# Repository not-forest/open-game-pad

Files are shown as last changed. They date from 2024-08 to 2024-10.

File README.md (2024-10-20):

# Open Game Pad

Low-cost, DIY game controller. This project enables anyone to build a custom game pad using affordable components and open hardware principles. The repository contains all necessary files, including PCB designs and firmware.

## Contents
- `pcb/`: PCB design files
- `src/`: Firmware source code
- `usbdrv/`: USB driver files
- `docs/`: Images

## Images

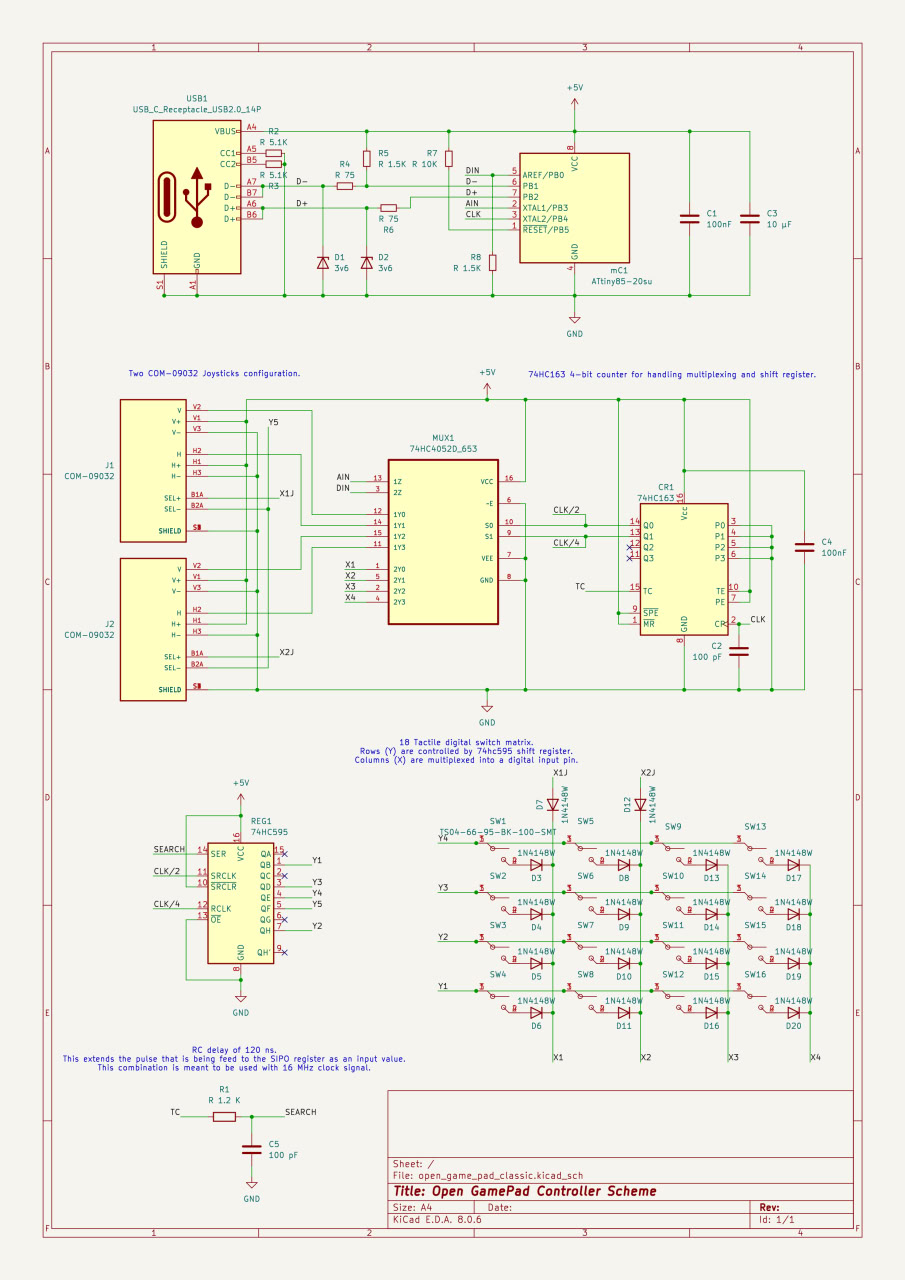
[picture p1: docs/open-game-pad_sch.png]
Schematic

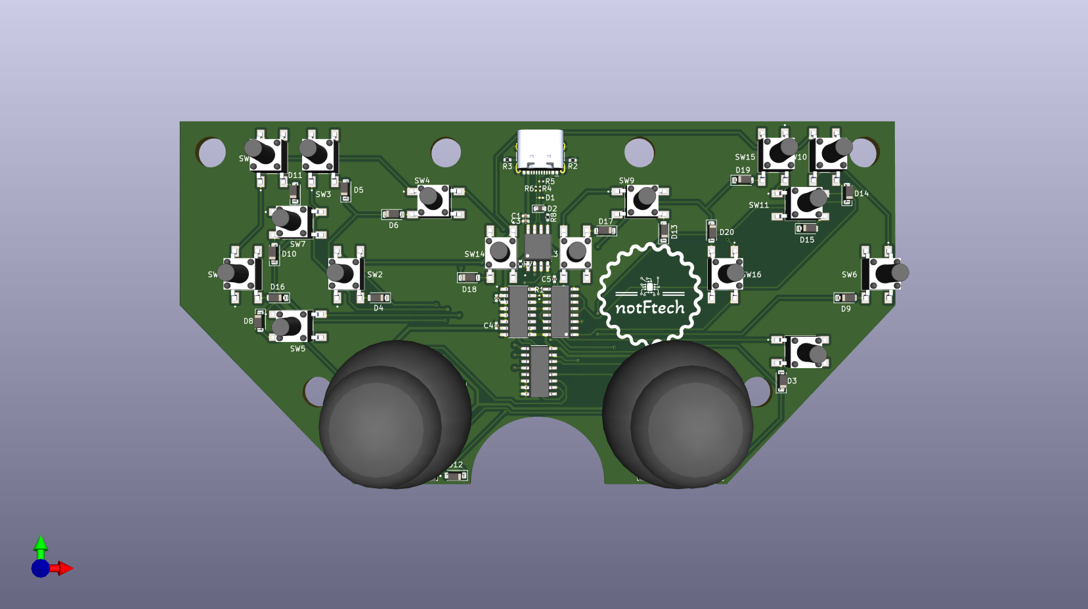
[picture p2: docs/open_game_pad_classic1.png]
View 1

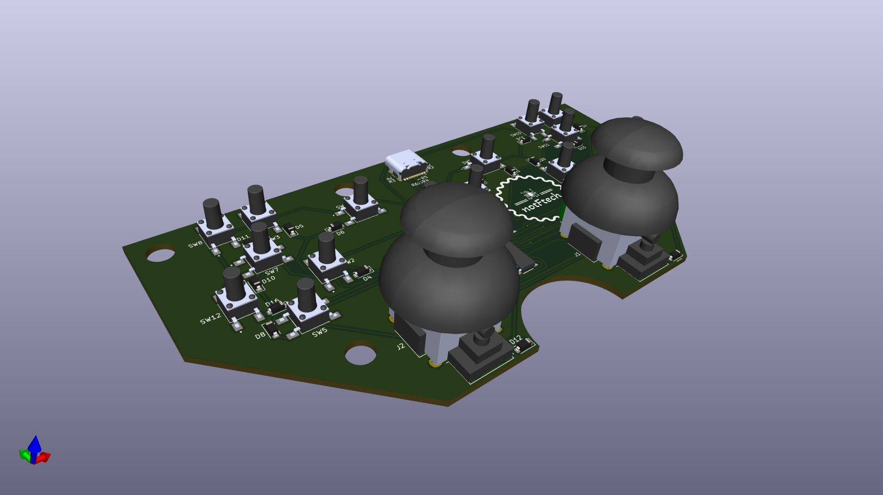
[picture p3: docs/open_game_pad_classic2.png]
View 2

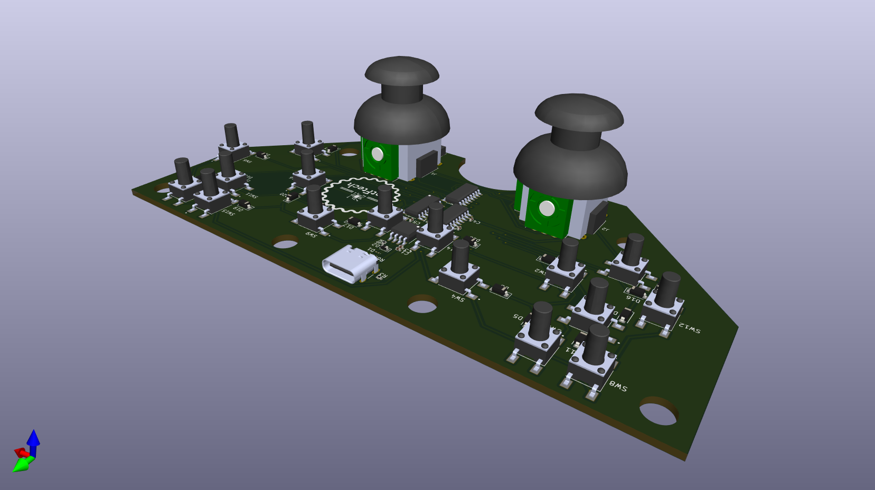
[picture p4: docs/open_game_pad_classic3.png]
View 3


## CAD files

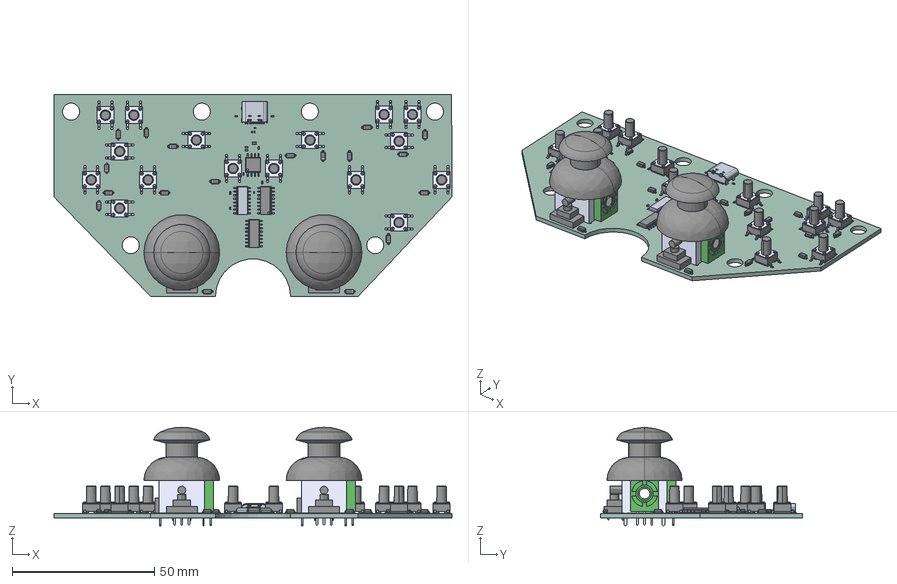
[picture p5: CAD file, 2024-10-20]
pcb/open_game_pad_classic/open_game_pad_classic.step
140.0 x 71.0 x 34.7 mm
R_0402_1005Metric x 4
C_0402_1005Metric x 5
D_SOD_123 x 18
TS04-66-95-BK-100-SMT x 16
DS90C031TM
D_0603
D16
74HC390D,652
ATTINY85-20SU
COM-09032 x 2
R_0201_0603Metric x 4
TYPE-C-31-M-12
open_game_pad_classic_PCB

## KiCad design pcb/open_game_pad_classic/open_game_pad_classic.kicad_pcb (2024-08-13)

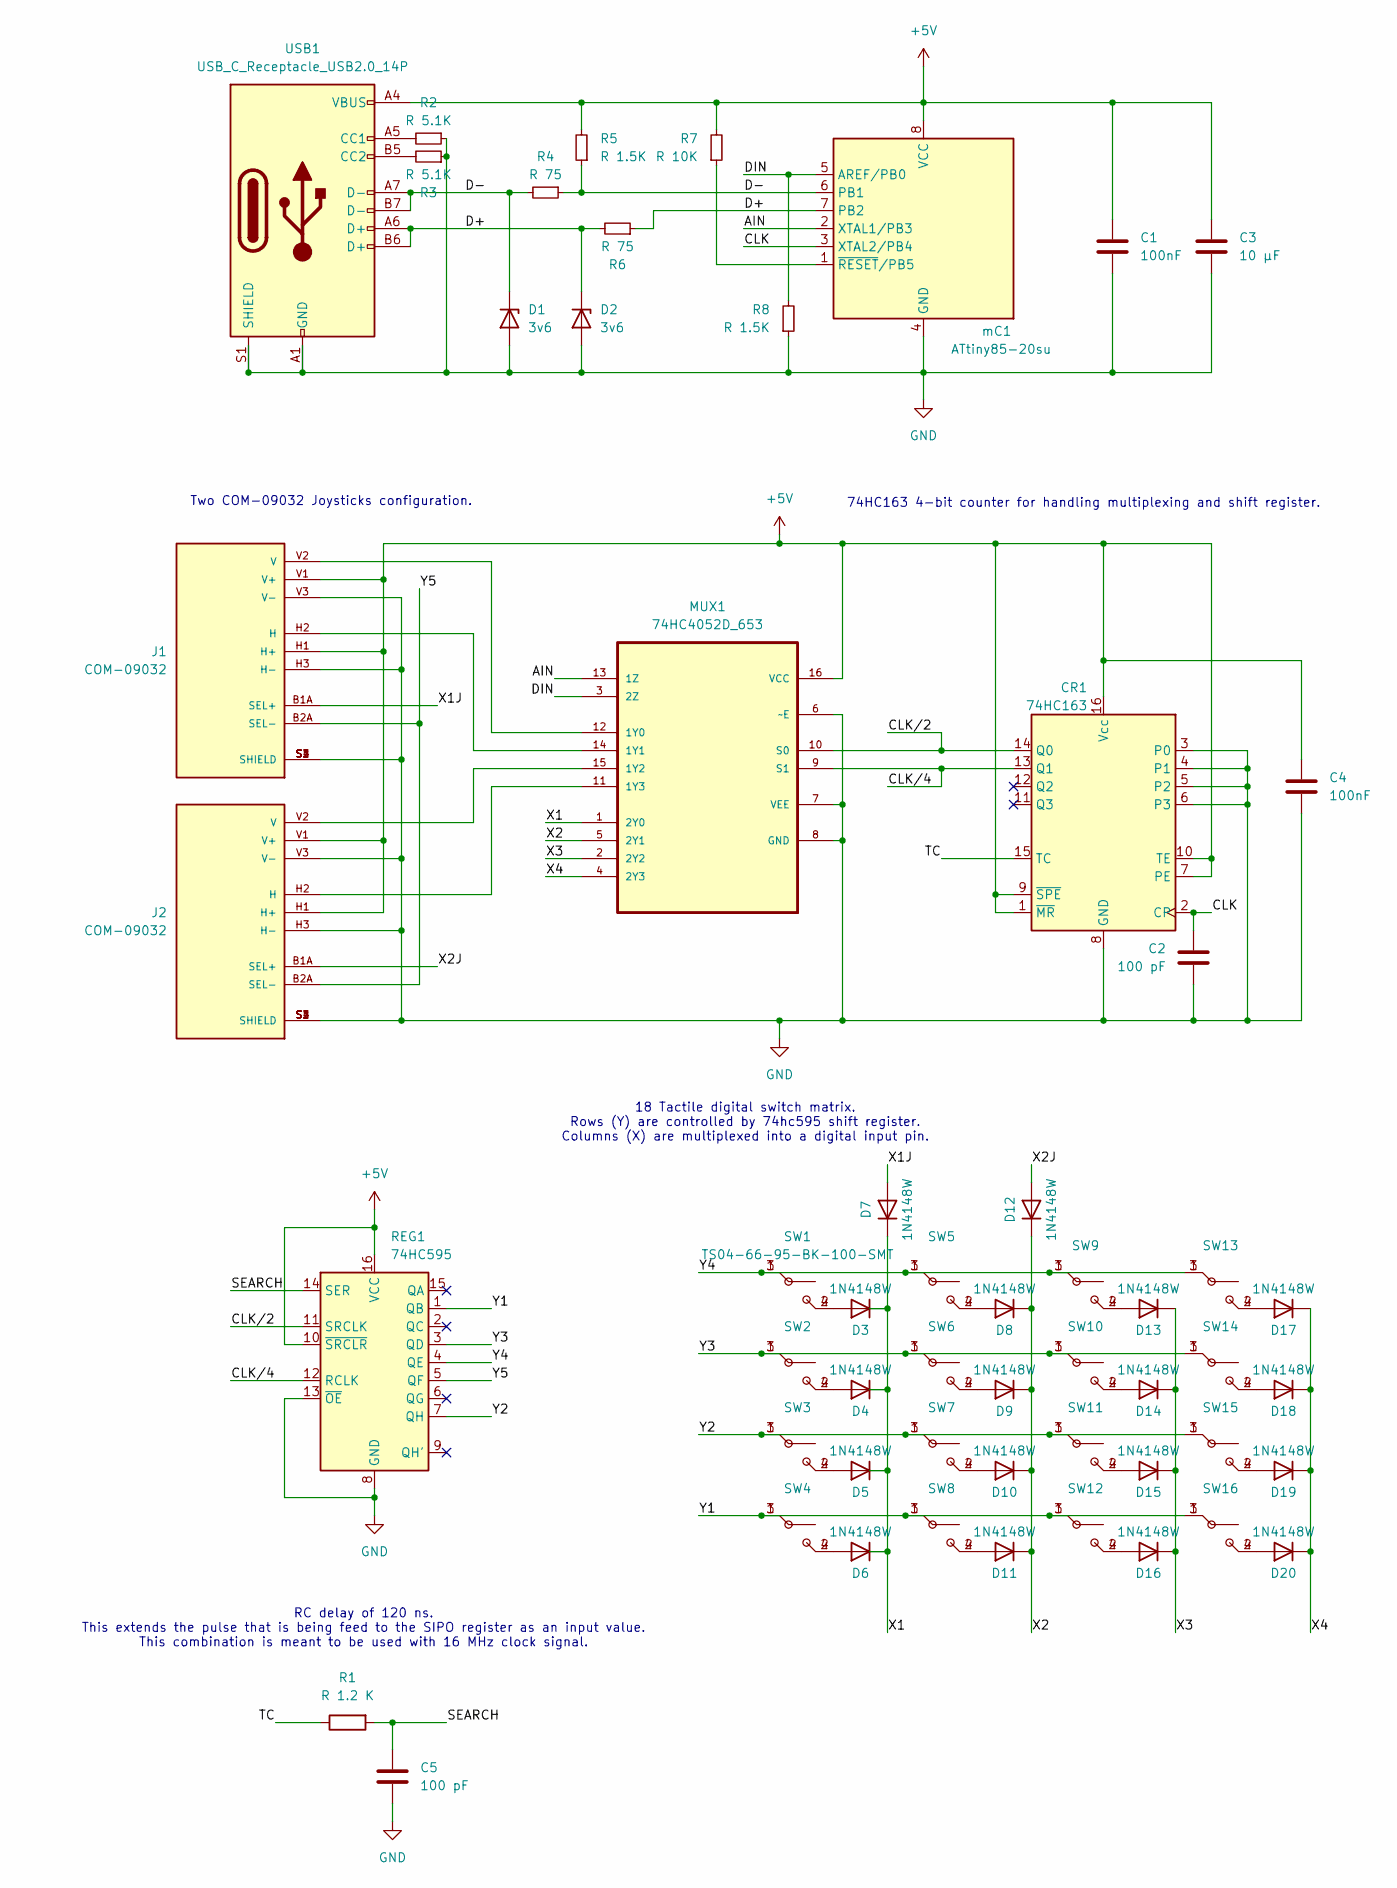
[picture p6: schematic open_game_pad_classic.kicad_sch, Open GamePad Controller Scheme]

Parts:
C1, C4: 100nF; C_0402_1005Metric
C2, C5: 100 pF; C_0402_1005Metric
C3: 10 µF; C_0402_1005Metric
CR1: 74HC163; SOIC127P600X175-16N
D1: 3v6; D_0201_0603Metric
D2: 3v6; D_0603_1608Metric
D3, D4, D5, D6, D7, D8, D9, D10, D11, D12, D13, D14, D15, D16, D17, D18, D19, D20: 1N4148W; D_SOD-123
J1, J2: COM-09032; XDCR_COM-09032; PARTREV N/A
MUX1: 74HC4052D_653; SOIC127P600X175-16N; MPN 74HC4052D,653
R1: R 1.2 K; R_0201_0603Metric
R2, R3: R 5.1K; R_0402_1005Metric
R4, R6: R 75; R_0201_0603Metric
R5: R 1.5K; R_0201_0603Metric
R7: R 10K; R_0402_1005Metric
R8: R 1.5K; R_0402_1005Metric
REG1: 74HC595; SOIC127P600X175-16N
SW1: TS04-66-95-BK-100-SMT; SW_TS04-66-95-BK-100-SMT
SW2, SW3, SW4, SW5, SW6, SW7, SW8, SW9, SW10, SW11, SW12, SW13, SW14, SW15, SW16: SW_TS04-66-95-BK-100-SMT
USB1: USB_C_Receptacle_USB2.0_14P; USB_C_Receptacle_HCTL_HC-TYPE-C-16P-01A
mC1: ATtiny85-20su; SOIC127P798X216-8N

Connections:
+5V: C1.1, C3.1, C4.1, CR1.1 (~MR), CR1.7 (PE), CR1.9 (~SPE), CR1.10 (TE), CR1.16 (Vcc), J1.H1 (H+), J1.V1 (V+), J2.H1 (H+), J2.V1 (V+), MUX1.16 (VCC), R5.2, R7.2, REG1.10 (~SRCLR), REG1.16 (VCC), USB1.A4 (VBUS), USB1.A9 (VBUS), USB1.B4 (VBUS), USB1.B9 (VBUS), mC1.8 (VCC)
/AIN: MUX1.13 (1Z), mC1.2 (XTAL1/PB3)
/CLK: C2.1, CR1.2 (CP), mC1.3 (XTAL2/PB4)
/CLK/2: CR1.14 (Q0), MUX1.10 (S0), REG1.11 (SRCLK)
/CLK/4: CR1.13 (Q1), MUX1.9 (S1), REG1.12 (RCLK)
/D+: D2.1 (K), R6.1, R6.2, USB1.A6 (D+), USB1.B6 (D+), mC1.7 (PB2)
/D-: D1.1 (K), R4.1, R4.2, R5.1, USB1.A7 (D-), USB1.B7 (D-), mC1.6 (PB1)
/DIN: MUX1.3 (2Z), R8.2, mC1.5 (AREF/PB0)
/SEARCH: C5.1, R1.2, REG1.14 (SER)
/TC: CR1.15 (TC), R1.1
/X1: D3.1 (K), D4.1 (K), D5.1 (K), D6.1 (K), D7.1 (K), MUX1.1 (2Y0)
/X1J: D7.2 (A), J1.B1A (SEL+)
/X2: D8.1 (K), D9.1 (K), D10.1 (K), D11.1 (K), D12.1 (K), MUX1.5 (2Y1)
/X2J: D12.2 (A), J2.B1A (SEL+)
/X3: D13.1 (K), D14.1 (K), D15.1 (K), D16.1 (K), MUX1.2 (2Y2)
/X4: D17.1 (K), D18.1 (K), D19.1 (K), D20.1 (K), MUX1.4 (2Y3)
/Y1: REG1.1 (QB), SW4.1 (A), SW4.3 (B), SW8.1 (A), SW8.3 (B), SW12.1 (A), SW12.3 (B), SW16.1 (A), SW16.3 (B)
/Y2: REG1.7 (QH), SW3.1 (A), SW3.3 (B), SW7.1 (A), SW7.3 (B), SW11.1 (A), SW11.3 (B), SW15.1 (A), SW15.3 (B)
/Y3: REG1.3 (QD), SW2.1 (A), SW2.3 (B), SW6.1 (A), SW6.3 (B), SW10.1 (A), SW10.3 (B), SW14.1 (A), SW14.3 (B)
/Y4: REG1.4 (QE), SW1.1 (A), SW1.3 (B), SW5.1 (A), SW5.3 (B), SW9.1 (A), SW9.3 (B), SW13.1 (A), SW13.3 (B)
/Y5: J1.B2A (SEL-), J2.B2A (SEL-), REG1.5 (QF)
GND: C1.2, C2.2, C3.2, C4.2, C5.2, CR1.3 (P0), CR1.4 (P1), CR1.5 (P2), CR1.6 (P3), CR1.8 (GND), D1.2 (A), D2.2 (A), J1.H3 (H-), J1.S1 (SHIELD), J1.S2 (SHIELD), J1.S3 (SHIELD), J1.S4 (SHIELD), J1.V3 (V-), J2.H3 (H-), J2.S1 (SHIELD), J2.S2 (SHIELD), J2.S3 (SHIELD), J2.S4 (SHIELD), J2.V3 (V-), MUX1.6 (~E), MUX1.7 (VEE), MUX1.8 (GND), R2.1, R3.1, R8.1, REG1.8 (GND), REG1.13 (~OE), USB1.A1 (GND), USB1.A12 (GND), USB1.B1 (GND), USB1.B12 (GND), USB1.S1 (SHIELD), mC1.4 (GND)
unnamed: D3.2 (A), SW1.2 (A), SW1.4 (B)
unnamed: D4.2 (A), SW2.2 (A), SW2.4 (B)
unnamed: D5.2 (A), SW3.2 (A), SW3.4 (B)
unnamed: D6.2 (A), SW4.2 (A), SW4.4 (B)
unnamed: D8.2 (A), SW5.2 (A), SW5.4 (B)
unnamed: D9.2 (A), SW6.2 (A), SW6.4 (B)
unnamed: D10.2 (A), SW7.2 (A), SW7.4 (B)
unnamed: D11.2 (A), SW8.2 (A), SW8.4 (B)
unnamed: D13.2 (A), SW9.2 (A), SW9.4 (B)
unnamed: D14.2 (A), SW10.2 (A), SW10.4 (B)
unnamed: D15.2 (A), SW11.2 (A), SW11.4 (B)
unnamed: D16.2 (A), SW12.2 (A), SW12.4 (B)
unnamed: D17.2 (A), SW13.2 (A), SW13.4 (B)
unnamed: D18.2 (A), SW14.2 (A), SW14.4 (B)
unnamed: D19.2 (A), SW15.2 (A), SW15.4 (B)
unnamed: D20.2 (A), SW16.2 (A), SW16.4 (B)
unnamed: J1.H2 (H), MUX1.14 (1Y1)
unnamed: J1.V2 (V), MUX1.12 (1Y0)
unnamed: J2.H2 (H), MUX1.11 (1Y3)
unnamed: J2.V2 (V), MUX1.15 (1Y2)
unnamed: R2.2, USB1.A5 (CC1)
unnamed: R3.2, USB1.B5 (CC2)
unnamed: R7.1, mC1.1 (~RESET/PB5)

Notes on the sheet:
18 Tactile digital switch matrix. Rows (Y) are controlled by 74hc595 shift register. Columns (X) are multiplexed into a digital input pin.
74HC163 4-bit counter for handling multiplexing and shift register.
RC delay of 120 ns. This extends the pulse that is being feed to the SIPO register as an input value. This combination is meant to be used with 16 MHz clock signal.
Two COM-09032 Joysticks configuration.

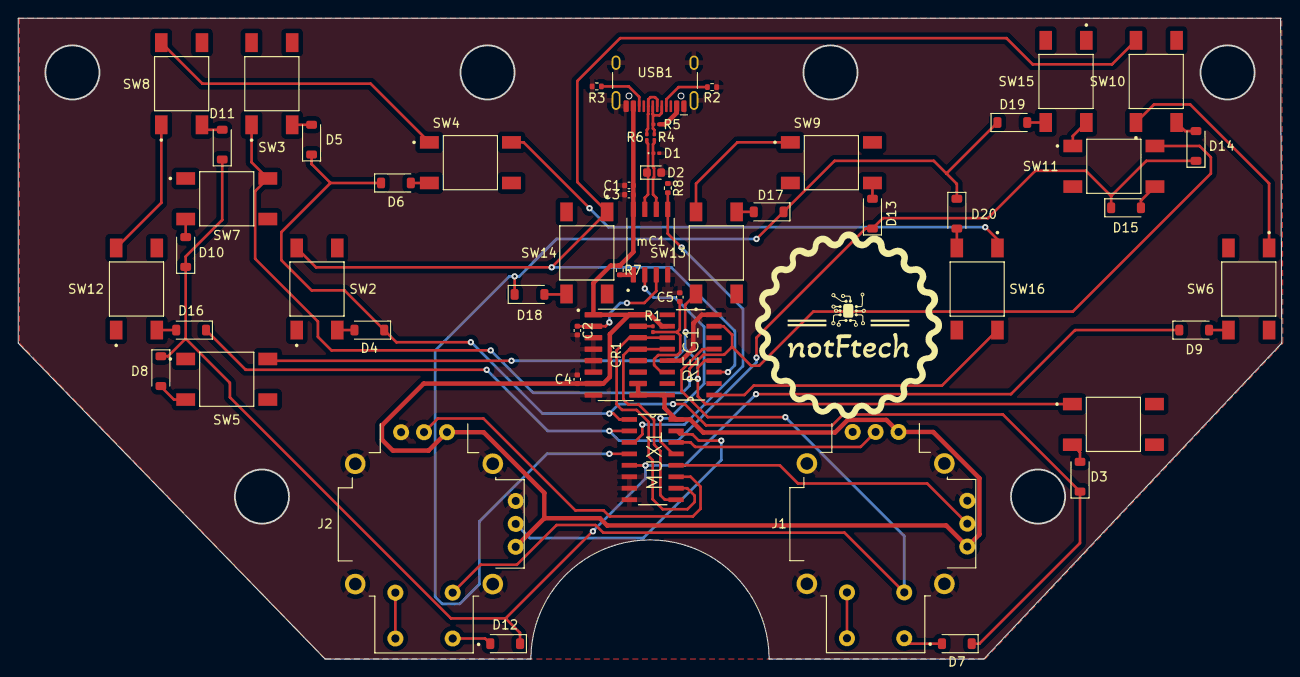
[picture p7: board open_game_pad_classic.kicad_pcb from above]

Board: 2 copper layers, 140.0 x 71.0 mm, 56 parts (0 on the bottom side), 45 nets.

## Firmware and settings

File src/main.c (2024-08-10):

/* 
 *  Main firmware code for 'Open Game Pad'
 *
 *  This code defines all necessary functions and stuctures for operating data between input sensors and output USB connector.
 *  The code is interrupt driven, therefore all necessary initialization part can be found in main function, while the rest is
 *  located in ISR definitions. V-USB library is a main driver for communicating with a host device as a hid device.
 *
 * */
 
#include<avr/pgmspace.h>
#include<avr/interrupt.h>

#include<avr/delay.h>
#include<avr/wdt.h>
#include<avr/io.h>

#include "../usbdrv/usbdrv.h"
#include "ogpad.h"

// Pointer to the REPORT structure.
static report_t *RPTR = &REPORT;
// Determines how often the device should send a report to the host when there is no change in the state of the inputs.
static uchar IDLE_RATE;
// Inpur counter allows to define which key we are reading as a digital input or which axis as an analog input.
static volatile inputCounter ic = { .raw = 0 };

/* 
 * Game Pad report descriptor. 
 *
 * It defines a device's buttons and joysticks via USB report descriptor. 
 * */
PROGMEM const char usbDescriptorHidReport[USB_CFG_HID_REPORT_DESCRIPTOR_LENGTH] = {
    // Global information.
    0x05, 0x01,                    // USAGE_PAGE (Generic Desktop)
    0x09, 0x05,                    // USAGE (Gamepad)
    0xA1, 0x01,                    // COLLECTION (Application)
    0xA1, 0x00,                    //   COLLECTION (Physical)
    // 18 buttons handling.
    0x05, 0x09,                    //     USAGE_PAGE (Button)
    0x19, 0x01,                    //     USAGE_MINIMUM (Button 1)
    0x29, 0x12,                    //     USAGE_MAXIMUM (Button 18)
    0x15, 0x00,                    //     LOGICAL_MINIMUM (0)
    0x25, 0x01,                    //     LOGICAL_MAXIMUM (1)
    0x95, 0x12,                    //     REPORT_COUNT (18)
    0x75, 0x01,                    //     REPORT_SIZE (1)
    0x81, 0x02,                    //     INPUT (Data,Var,Abs)
    // Unused bits are ignored.
    0x95, 0x01,                    //     REPORT_COUNT (1)
    0x75, 0x0D,                    //     REPORT_SIZE (14)
    0x81, 0x03,                    //     INPUT (Cnst,Var,Abs)
    // Joysticks handling.
    0x05, 0x01,                    //     USAGE_PAGE (Generic Desktop)
    0x09, 0x30,                    //     USAGE (X)
    0x09, 0x31,                    //     USAGE (Y)
    0x09, 0x32,                    //     USAGE (Z)
    0x09, 0x33,                    //     USAGE (Rx)
    0x15, 0x81,                    //     LOGICAL_MINIMUM (-127)
    0x25, 0x7F,                    //     LOGICAL_MAXIMUM (127)
    0x75, 0x08,                    //     REPORT_SIZE (8)
    0x95, 0x04,                    //     REPORT_COUNT (4)
    0x81, 0x02,                    //     INPUT (Data,Var,Abs)
    // Closing collections.
    0xC0,                          //   END_COLLECTION
    0xC0                           // END_COLLECTION
};

// This is the function from the V-USB library that must be defined here to properly handle the requests from the host.
usbMsgLen_t usbFunctionSetup(uchar raw[8]) {
    usbRequest_t *req = (void *) raw;

    // Class request type.
    if((req->bmRequestType & USBRQ_TYPE_MASK) == USBRQ_TYPE_CLASS){
        if(req->bRequest == USBRQ_HID_GET_REPORT){  /* wValue: ReportType (highbyte), ReportID (lowbyte) */
            // we only have one report type, so don't look at wValue
            usbMsgPtr = (void *) RPTR;
            return sizeof(REPORT);
        }else if(req->bRequest == USBRQ_HID_GET_IDLE){
            usbMsgPtr = &IDLE_RATE;
            return 1;
        }else if(req->bRequest == USBRQ_HID_SET_IDLE){
            IDLE_RATE = req->wValue.bytes[1];
        }
    }else{
        /* Vendor specific requests could be implemented here to built up the firmware abilities. */
    } 

    return 0;
}

#define abs(x) ((x) > 0 ? (x) : (-x))

// Calibrates the RC oscillator to 16.5 MHz speeds.
void hadUsbReset(void) {
    int frameLength, targetLength = (unsigned)(1499 * (double)F_CPU / 10.5e6 + 0.5);
    int bestDeviation = 9999;
    uchar trialCal, bestCal, step, region;

    // do a binary search in regions 0-127 and 128-255 to get optimum OSCCAL
    for(region = 0; region <= 1; region++) {
        frameLength = 0;
        trialCal = (region == 0) ? 0 : 128;
        
        for(step = 64; step > 0; step >>= 1) { 
            if(frameLength < targetLength) // true for initial iteration
                trialCal += step; // frequency too low
            else
                trialCal -= step; // frequency too high
                
            OSCCAL = trialCal;

            cli();
            frameLength = usbMeasureFrameLength();
            sei();

            if(abs(frameLength-targetLength) < bestDeviation) {
                bestCal = trialCal; // new optimum found
                bestDeviation = abs(frameLength -targetLength);
            }
        }
    }

    OSCCAL = bestCal;
}

// Main function that initializes registers with required values and then waits for interrupts.
int __attribute__((noreturn)) main(void) {
    wdt_disable();
    /*      GPIO Configuration      */
    // PB1, PB2 lines are handled by V-USB. PB0 is a digital input line by default. 
    // The clock is being bit-banged inside the ADC interrupt handler.
    DDRB = 1 << PB4;        // CLK output.
    PCMSK = 1 << PCINT0;    // The PCINT interrupt will be invoked only when something changes on PB0.

    /*      ADC Configuration       */
    // - Only 8 highest bits are required, therefore 1 Mhz sampling can be used for faster conversion. This sampling is a limit declared 
    // in the datasheet;
    // - Holding high bits in ADCH as a result;
    // - Single ended input with internal Vcc voltage reference is being used;
    ADCSRA = (1 << ADPS2) | (1 << ADSC) | (1 << ADIF);
    ADMUX = (1 << MUX1) | (1 << MUX0) | (1 << ADLAR);

    wdt_enable(WDTO_1S);                   // Enabling the watchdog timer and selecting the 1s expiring.
    
    usbDeviceDisconnect();                    // Forcing re-enumeration.
    wdt_reset();                           // One second is enough for the next step.
    uchar i = 0;
    while(--i){             // USB would be disconnected for 300 ms.
        wdt_reset();
        _delay_ms(1);
    }                       
    usbDeviceConnect();
    usbInit();                             // Start of USB handling.

    GIMSK = 1 << PCIE;
    // Main loop only handles the USB connection and resets the watchdog timer.
    sei();
    for(;;) {
        wdt_reset();
        usbPoll();                         // Polling the USB lines
        
        // Here we are sending the current data we have.
        if(usbInterruptIsReady()) {        // If interrupt is ready, sending the newest data.
            usbSetInterrupt((void *) RPTR, sizeof(REPORT));
        }
    }
}

/* 
 * This interrupt handles ADC data on AIN line. 
 *
 * It also does the output clock control by bitbanging, so all outside components are dependent on
 * ADC convertion. This way it is possible to decode all digital and analog inputs.
 * */
ISR(ADC_vect) {
    PORTB ^= (1 << PB4);                          // Clock tick.
    RPTR->joyax[ic.ANALOG] = ADCH;                // Writing the next analog input to the proper location.
    ADCSRA |= (1 << ADSC);                        // Starting new ADC conversion.
    ic.raw++;

    if(ic.raw > 18) ic.raw = 0;
}

/* 
 * Sets an interrupt for the PB0 pin. 
 * 
 * INT0 is reserved for the V-USB use. The PCINT[5..0] would cause this interrupt.
 * This handler detects a keypress obtained from the key matrix and iterates over each key to
 * define which key was pressed. All pressed keys are then saved into a mask and send via USB
 * connection.
 * */
ISR(PCINT0_vect) {
    RPTR->bmask = (PORTB & 1) << ic.DIGITAL;      // Marking the value in the button mask. This way several keys can be pressed in one loop.
}

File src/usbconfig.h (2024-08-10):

/* 
 *  Configuration header for V-USB library.
 *
 * This file is an example configuration (with inline documentation) for the USB 
 * driver. It configures V-USB for USB D+ connected to Port B bit 2 (which is                                                               also hardware interrupt 0 on many devices) and USB D- to Port B bit 1. You may
 * wire the lines to any other port, as long as D+ is also wired to INT0 (or any
 * other hardware interrupt, as long as it is the highest level interrupt, see
 * section at the end of this file).
 *
 * */

#ifndef __usbconfig_h_included__
#define __usbconfig_h_included__

/*
General Description:
*/

/* ---------------------------- Hardware Config ---------------------------- */

/* This is the port where the USB bus is connected. When you configure it to
 * "B", the registers PORTB, PINB and DDRB will be used.
 */
#define USB_CFG_IOPORTNAME      B
/* This is the bit number in USB_CFG_IOPORT where the USB D- line is connected.
 * This may be any bit in the port.
 */
#define USB_CFG_DMINUS_BIT      1
/* This is the bit number in USB_CFG_IOPORT where the USB D+ line is connected.
 * This may be any bit in the port. Please note that D+ must also be connected
 * to interrupt pin INT0! [You can also use other interrupts, see section
 * "Optional MCU Description" below, or you can connect D- to the interrupt, as
 * it is required if you use the USB_COUNT_SOF feature. If you use D- for the
 * interrupt, the USB interrupt will also be triggered at Start-Of-Frame
 * markers every millisecond.]
 */
#define USB_CFG_DPLUS_BIT       2
/* Clock rate of the AVR in kHz. Legal values are 12000, 12800, 15000, 16000,
 * 16500, 18000 and 20000. The 12.8 MHz and 16.5 MHz versions of the code
 * require no crystal, they tolerate +/- 1% deviation from the nominal
 * frequency. All other rates require a precision of 2000 ppm and thus a
 * crystal!
 * Since F_CPU should be defined to your actual clock rate anyway, you should
 * not need to modify this setting.
 */
#define USB_CFG_CLOCK_KHZ       (F_CPU/1000)
/* Define this to 1 if you want that the driver checks integrity of incoming
 * data packets (CRC checks). CRC checks cost quite a bit of code size and are
 * currently only available for 18 MHz crystal clock. You must choose
 * USB_CFG_CLOCK_KHZ = 18000 if you enable this option.
 */
#define USB_CFG_CHECK_CRC       0

/* ----------------------- Optional Hardware Config ------------------------ */

/* If you connect the 1.5k pullup resistor from D- to a port pin instead of
 * V+, you can connect and disconnect the device from firmware by calling
 * the macros usbDeviceConnect() and usbDeviceDisconnect() (see usbdrv.h).
 * This constant defines the port on which the pullup resistor is connected.
 */
/* #define USB_CFG_PULLUP_IOPORTNAME   D */
/* This constant defines the bit number in USB_CFG_PULLUP_IOPORT (defined
 * above) where the 1.5k pullup resistor is connected. See description
 * above for details.
 */
/* #define USB_CFG_PULLUP_BIT          4 */

/* --------------------------- Functional Range ---------------------------- */
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

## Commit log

2024-06-06 First PCB scheme version designed. Many changes possible
    [open_game_pad_classic.kicad_pcb, open_game_pad_classic.kicad_sch]
2024-06-07 Connected required libraries. Added the device report descriptor.
2024-06-07 Added more footprints for switches.
    [open_game_pad_classic.kicad_sch]
2024-06-10 Added an inverting amplifier circuit to convert a -2.5V +2.5V signal to 0V - 5V for further use in ADC converter.
    [open_game_pad_classic.kicad_sch]
2024-06-11 Minor changes to register values and their footprint
    [open_game_pad_classic.kicad_sch]
2024-06-19 Updated the PCB and scheme. 2-layered, ground plane.
    [open_game_pad_classic.kicad_pcb, open_game_pad_classic.kicad_sch]
2024-06-19 Implemented the starter main function logic. Changed the USB HID report descriptor to a version that is expected by a host device. Initializing the V-USB library.
2024-06-20 More decoupling for microcontroller and timer.
    [open_game_pad_classic.kicad_pcb, open_game_pad_classic.kicad_sch]
2024-06-20 Fixed the schematic on PISO read. Updated the PCB.
    [open_game_pad_classic.kicad_pcb, open_game_pad_classic.kicad_sch]
2024-06-20 Fixed the reset problem by adding an 8-tick delay.
    [open_game_pad_classic.kicad_pcb, open_game_pad_classic.kicad_sch]
2024-06-27 Removed the obsolete parts. Changed the logic completely to use one SIPO register. Using external counter to plex four analog and four digital inputs in one double 74hc4052.
    [open_game_pad_classic.kicad_sch]
2024-06-27 Imported footprints.
    [open_game_pad_classic.kicad_sch]
2024-06-28 Optimized the report structure so that overall size is a power of two.
2024-06-28 Changed the code based on new schematic. Updated the USB report based on new structure.
2024-06-29 Updated the PCB based on the new schematic design.
    [open_game_pad_classic.kicad_pcb, open_game_pad_classic.kicad_sch]
2024-06-30 Deleted uneccessary files.
    [open_game_pad_classic.kicad_pcb, open_game_pad_classic.kicad_sch]
2024-06-30 Added drill holes. Changes in design for better timing in a differential pair for USB transmision.
    [open_game_pad_classic.kicad_pcb]
2024-06-30 Added the logo.
    [open_game_pad_classic.kicad_pcb]
2024-07-01 Fixed the 3d models kicad bug.
    [open_game_pad_classic.kicad_pcb, open_game_pad_classic.kicad_sch]
2024-07-01 Removed the legacy version.
    [open_game_pad_classic.kicad_pcb, open_game_pad_classic.kicad_sch]
2024-07-09 Fixed the switches connections and remade the tracks in pcb.
    [open_game_pad_classic.kicad_pcb, open_game_pad_classic.kicad_sch]
2024-07-10 Fixed the schematic logic. Added a RC delay circuit to feed a short TC signal to the SIPO register. This allows for matrix scan based fully on clock. This component is intended to be used with ATtiny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
    [open_game_pad_classic.kicad_sch]
2024-08-10 Fixed the '16Mhz' fuse.
2024-08-10 Changed the USB poll interval and maximal power consumed by usb bus. Added a reset hook reference for reset RC calibration function.
    [usbconfig.h]
2024-08-10 Added a function that calibrates 16.5MHz by optimizing OSCCAL value in two regions.
2024-08-13 Updates the PCB according to new schematic.
    [open_game_pad_classic.kicad_pcb, open_game_pad_classic.kicad_sch]
2024-10-20 Added readme and images.
    [open_game_pad_classic.step]
